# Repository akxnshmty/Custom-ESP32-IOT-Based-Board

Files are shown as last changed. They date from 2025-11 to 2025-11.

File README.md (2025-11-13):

# Custom-ESP32-IOT-Based-Board
Custom Multi-Sensor IoT Board with SD Card, Flash Memory, Microphone & High-Speed Routing

This project is a fully custom 4-layer IoT development board built around the ESP32, integrating multiple peripherals such as an SD card interface, external flash memory, I²C sensors, and an onboard microphone. It is designed as a compact, enclosure-ready hardware platform suitable for embedded, IoT, and data-logging applications.

⸻

🚀 Features
	•	ESP32-WROOM based core controller
	•	SD Card interface for data logging
	•	Flash memory IC for additional storage
	•	On-board microphone for audio input
	•	I²C sensor interface for environmental/IMU sensors
	•	User GPIO headers for expansion
	•	4-layer PCB with dedicated ground and power planes
	•	Mounting holes for enclosure integration
	•	Custom 3D models for accurate visualization
	•	Manual routing (0% autorouter) for full design control

⸻

🧩 Hardware Overview

4-Layer Stackup
	•	Layer 1 (Top): Components + High-speed signal routing
	•	Layer 2: Solid GND plane for low-noise return paths
	•	Layer 3: Power plane (5V + 3.3V distribution)
	•	Layer 4 (Bottom): Signal routing + copper zones

This architecture improves signal integrity, noise immunity, and routing efficiency, especially for the SD card, flash memory, and microphone circuits.

⸻

🔧 Key Technical Highlights

Manual Routing
	•	Differential pair routing
	•	Length matching for timing-critical nets
	•	I²C bus routing for sensors
	•	High-speed clock lines
	•	Optimized power traces
	•	Dedicated copper zones for GND and power
	•	Via stitching for ground reinforcement

Design & Validation
	•	Full manual DRC debugging
	•	Fixed annular ring and clearance violations
	•	Added test points, accessible GPIO, and labeled connectors
	•	Optimized analog routing for microphone stage

Mechanical Integration
	•	Exported STEP and WRL models
	•	Assembled 3D view for enclosure planning
	•	Added mounting holes
	•	Custom silkscreen signature

Firmware (Coming Soon)
	•	SD card logging demo
	•	Sensor reading script (I²C)
	•	Microphone input test
	•	Wi-Fi provisioning & OTA updates

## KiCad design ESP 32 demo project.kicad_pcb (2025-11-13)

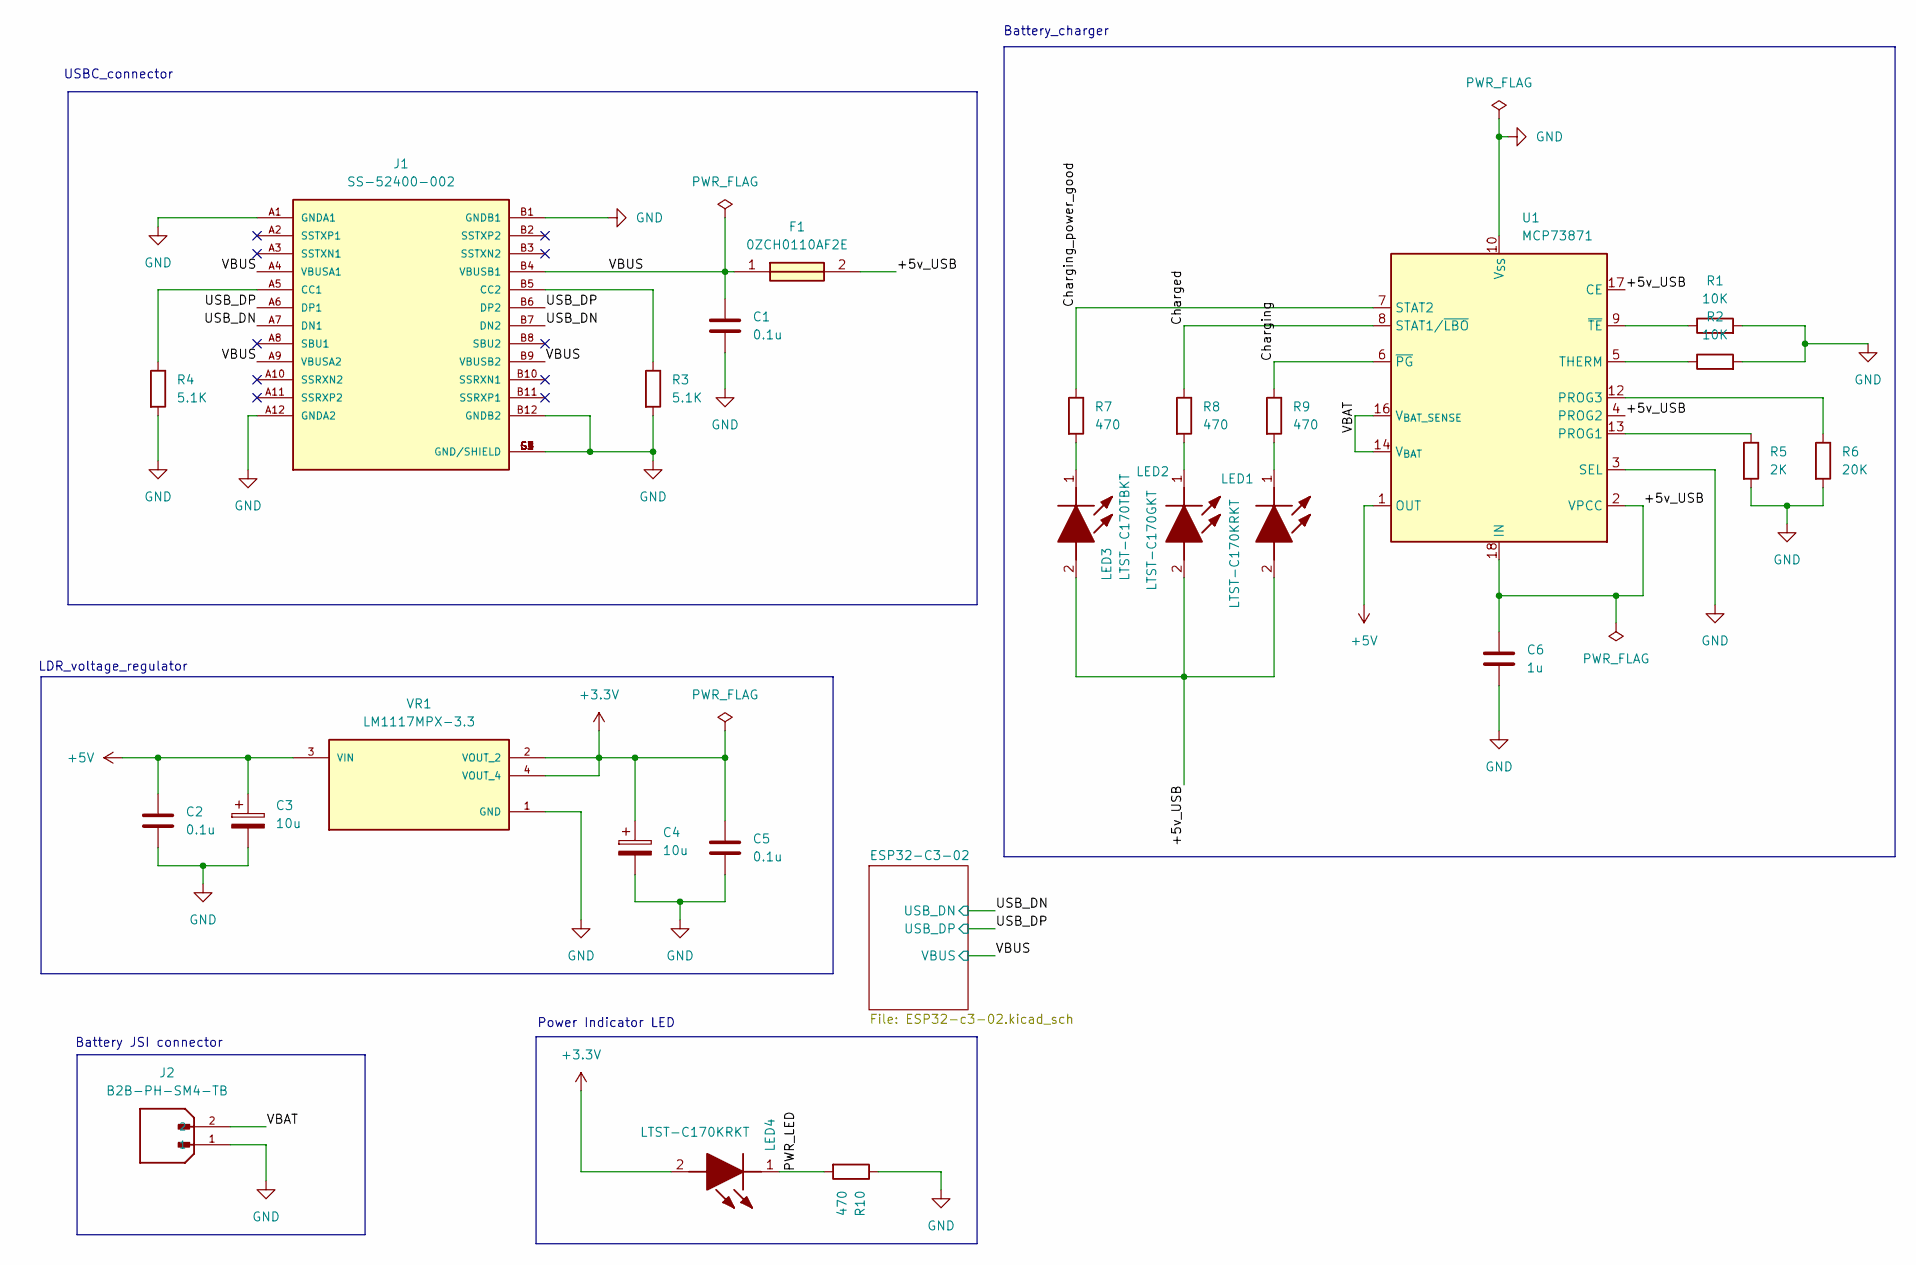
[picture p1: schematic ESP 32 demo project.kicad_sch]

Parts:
C1, C2, C5: 0.1u; C_0805_2012Metric
C3, C4: 10u; T491A
C6: 1u; C_0805_2012Metric
F1: 0ZCH0110AF2E; FUSC3226X100N; Manufacturer_Part_Number 0ZCH0110AF2E
J1: SS-52400-002; BELFUSE_SS-52400-002; PARTREV A0
J2: B2B-PH-SM4-TB; JST_B2B-PH-SM4-TB; PARTREV N/A
LED1, LED4: LTST-C170KRKT; LEDC2012X120N; Manufacturer_Part_Number LTST-C170KRKT; Mouser Part Number 859-LTST-C170KRKT
LED2: LTST-C170GKT; LEDC2012X120N; Manufacturer_Part_Number LTST-C170GKT; Mouser Part Number 859-LTST-C170GKT
LED3: LTST-C170TBKT; LEDC2012X120N; Manufacturer_Part_Number LTST-C170TBKT; Mouser Part Number 859-LTST-C170TBKT
R1, R2: 10K; R_0805_2012Metric
R3, R4: 5.1K; R_0805_2012Metric
R5: 2K; R_0805_2012Metric
R6: 20K; R_0805_2012Metric
R7, R8, R9, R10: 470; R_0805_2012Metric
U1: MCP73871; QFN-20-1EP_4x4mm_P0.5mm_EP2.5x2.5mm
VR1: LM1117MPX-3.3; VREG_LM1117MPX-3.3

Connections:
+3.3V: C4.1, C5.1, LED4.2 (A), VR1.2 (VOUT_2), VR1.4 (VOUT_4); also elsewhere on the board
/Charged: R8.1, U1.8 (STAT1/~LBO)
/Charging: R9.1, U1.6 (~PG)
/Charging_power_good: R7.1, U1.7 (STAT2)
/PWR_LED: LED4.1 (K), R10.2; also elsewhere on the board
/USB_DN: J1.A7 (DN1), J1.B7 (DN2); also elsewhere on the board
/USB_DP: J1.A6 (DP1), J1.B6 (DP2); also elsewhere on the board
/VBAT: J2.2, U1.14 (V_{BAT}), U1.15 (V_{BAT}), U1.16 (V_{BAT_SENSE})
/VBUS: C1.1, F1.1, J1.A4 (VBUSA1), J1.A9 (VBUSA2), J1.B4 (VBUSB1), J1.B9 (VBUSB2); also elsewhere on the board
unnamed: J1.A5 (CC1), R4.1
unnamed: J1.B5 (CC2), R3.1
unnamed: LED1.1 (K), R9.2
unnamed: LED2.1 (K), R8.2
unnamed: LED3.1 (K), R7.2
unnamed: R5.1, U1.13 (PROG1)
unnamed: R6.1, U1.12 (PROG3)
unnamed: R2.1, U1.5 (THERM)
unnamed: R1.1, U1.9 (~TE)

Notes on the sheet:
Battery JSI connector
Power Indicator LED
LDR_voltage_regulator
Battery_charger
USBC_connector

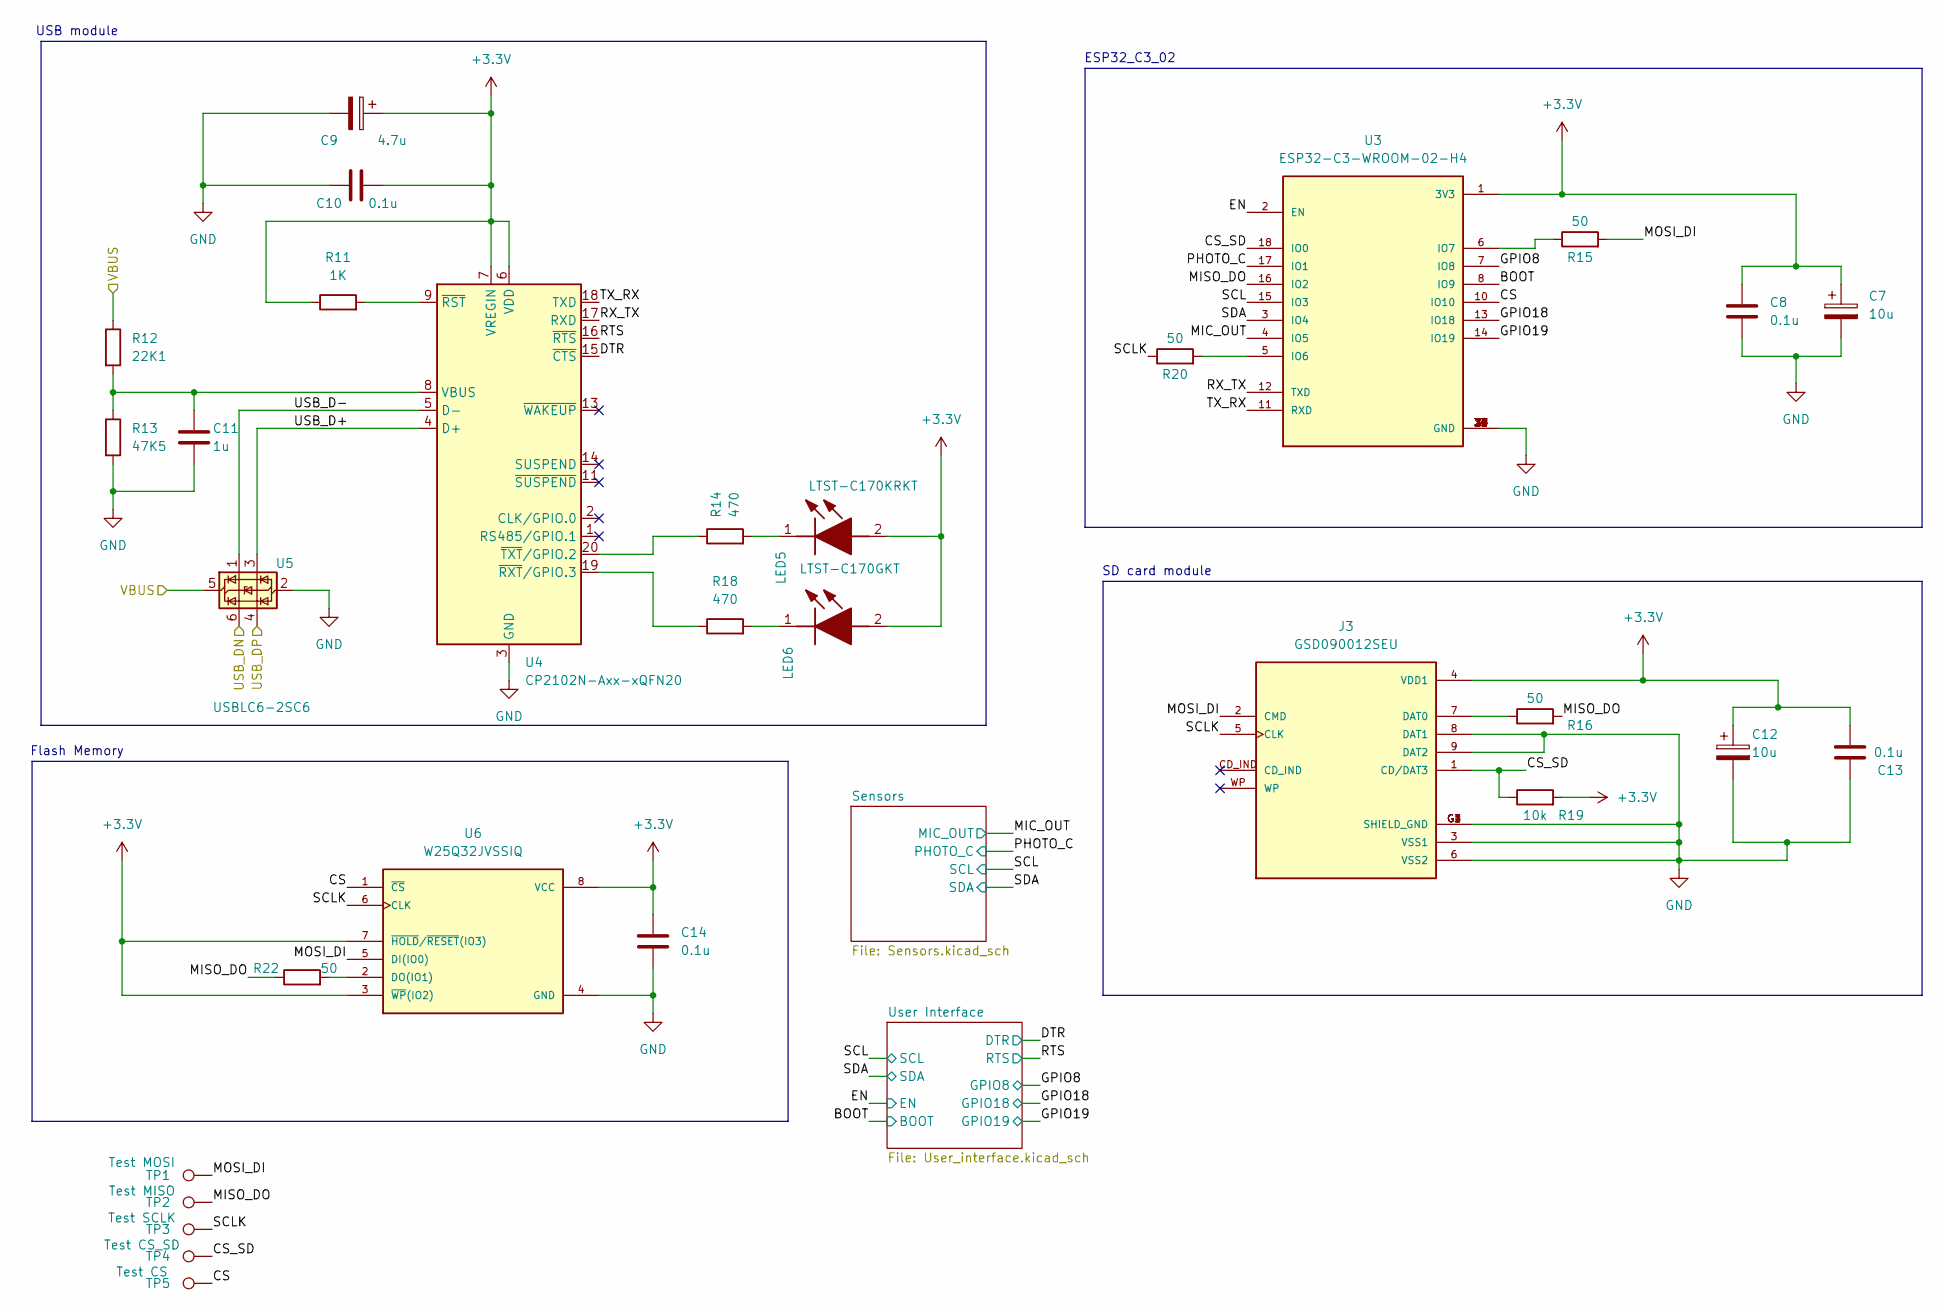
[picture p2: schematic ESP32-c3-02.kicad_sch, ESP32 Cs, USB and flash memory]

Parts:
C7, C12: 10u; T491A
C8, C10, C13, C14: 0.1u; C_0805_2012Metric
C9: 4.7u; T491A
C11: 1u; C_0805_2012Metric
J3: GSD090012SEU; AMPHENOL_GSD090012SEU; PARTREV E
LED5: LTST-C170GKT; LEDC2012X120N; Manufacturer_Part_Number LTST-C170GKT; Mouser Part Number 859-LTST-C170GKT
LED6: LTST-C170KRKT; LEDC2012X120N; Manufacturer_Part_Number LTST-C170KRKT; Mouser Part Number 859-LTST-C170KRKT
R11: 1K; R_0805_2012Metric
R12: 22K1; R_0805_2012Metric
R13: 47K5; R_0805_2012Metric
R14, R18: 470; R_0805_2012Metric
R15, R16, R20, R22: 50; R_0805_2012Metric
R19: 10k; R_0805_2012Metric
TP1: Test MOSI; TestPoint_Pad_D1.0mm
TP2: Test MISO; TestPoint_Pad_D1.0mm
TP3: Test SCLK; TestPoint_Pad_D1.0mm
TP4: Test CS_SD; TestPoint_Pad_D1.0mm
TP5: Test CS; TestPoint_Pad_D1.0mm
U3: ESP32-C3-WROOM-02-H4; MODULE_ESP32-C3-WROOM-02-H4
U4: CP2102N-Axx-xQFN20; SiliconLabs_QFN-20-1EP_3x3mm_P0.5mm_EP1.8x1.8mm
U5: USBLC6-2SC6; SOT-23-6
U6: W25Q32JVSSIQ; SOIC127P790X216-8N; M_PART_NUMBER W25QXX

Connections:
+3.3V: C7.1, C8.1, C9.1, C10.1, C12.1, C13.2, C14.1, J3.4 (VDD1), LED5.2 (A), LED6.2 (A), R11.1, R19.2, U3.1 (3V3), U4.6 (VDD), U4.7 (VREGIN), U6.3 (~WP(IO2)), U6.7 (~HOLD/~RESET(IO3)), U6.8 (VCC); also elsewhere on the board
/ESP32-C3-02/BOOT: U3.8 (IO9); also elsewhere on the board
/ESP32-C3-02/CS: TP5.1, U3.10 (IO10), U6.1 (~CS)
/ESP32-C3-02/CS_SD: J3.1 (CD/DAT3), R19.1, TP4.1, U3.18 (IO0)
/ESP32-C3-02/DTR: U4.15 (~CTS); also elsewhere on the board
/ESP32-C3-02/EN: U3.2 (EN); also elsewhere on the board
/ESP32-C3-02/GPIO8: U3.7 (IO8); also elsewhere on the board
/ESP32-C3-02/GPIO18: U3.13 (IO18); also elsewhere on the board
/ESP32-C3-02/GPIO19: U3.14 (IO19); also elsewhere on the board
/ESP32-C3-02/MIC_OUT: U3.4 (IO5); also elsewhere on the board
/ESP32-C3-02/MISO_DO: R16.2, R22.1, TP2.1, U3.16 (IO2)
/ESP32-C3-02/MOSI_DI: J3.2 (CMD), R15.2, TP1.1, U6.5 (DI(IO0))
/ESP32-C3-02/PHOTO_C: U3.17 (IO1); also elsewhere on the board
/ESP32-C3-02/RTS: U4.16 (~RTS); also elsewhere on the board
/ESP32-C3-02/RX_TX: U3.12 (TXD), U4.17 (RXD)
/ESP32-C3-02/SCL: U3.15 (IO3); also elsewhere on the board
/ESP32-C3-02/SCLK: J3.5 (CLK), R20.1, TP3.1, U6.6 (CLK)
/ESP32-C3-02/SDA: U3.3 (IO4); also elsewhere on the board
/ESP32-C3-02/TX_RX: U3.11 (RXD), U4.18 (TXD)
/ESP32-C3-02/USB_D+: U4.4 (D+), U5.3 (I/O2)
/ESP32-C3-02/USB_D-: U4.5 (D-), U5.1 (I/O1)
/USB_DN: U5.6 (I/O1); also elsewhere on the board
/USB_DP: U5.4 (I/O2); also elsewhere on the board
/VBUS: R12.1, U5.5 (VBUS); also elsewhere on the board
unnamed: J3.7 (DAT0), R16.1
unnamed: LED5.1 (K), R14.2
unnamed: LED6.1 (K), R18.2
unnamed: R20.2, U3.5 (IO6)
unnamed: R15.1, U3.6 (IO7)
unnamed: C11.1, R12.2, R13.1, U4.8 (VBUS)
unnamed: R11.2, U4.9 (~RST)
unnamed: R18.1, U4.19 (~RXT/GPIO.3)
unnamed: R14.1, U4.20 (~TXT/GPIO.2)
unnamed: R22.2, U6.2 (DO(IO1))

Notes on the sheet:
Flash Memory
ESP32_C3_02
SD card module
USB module

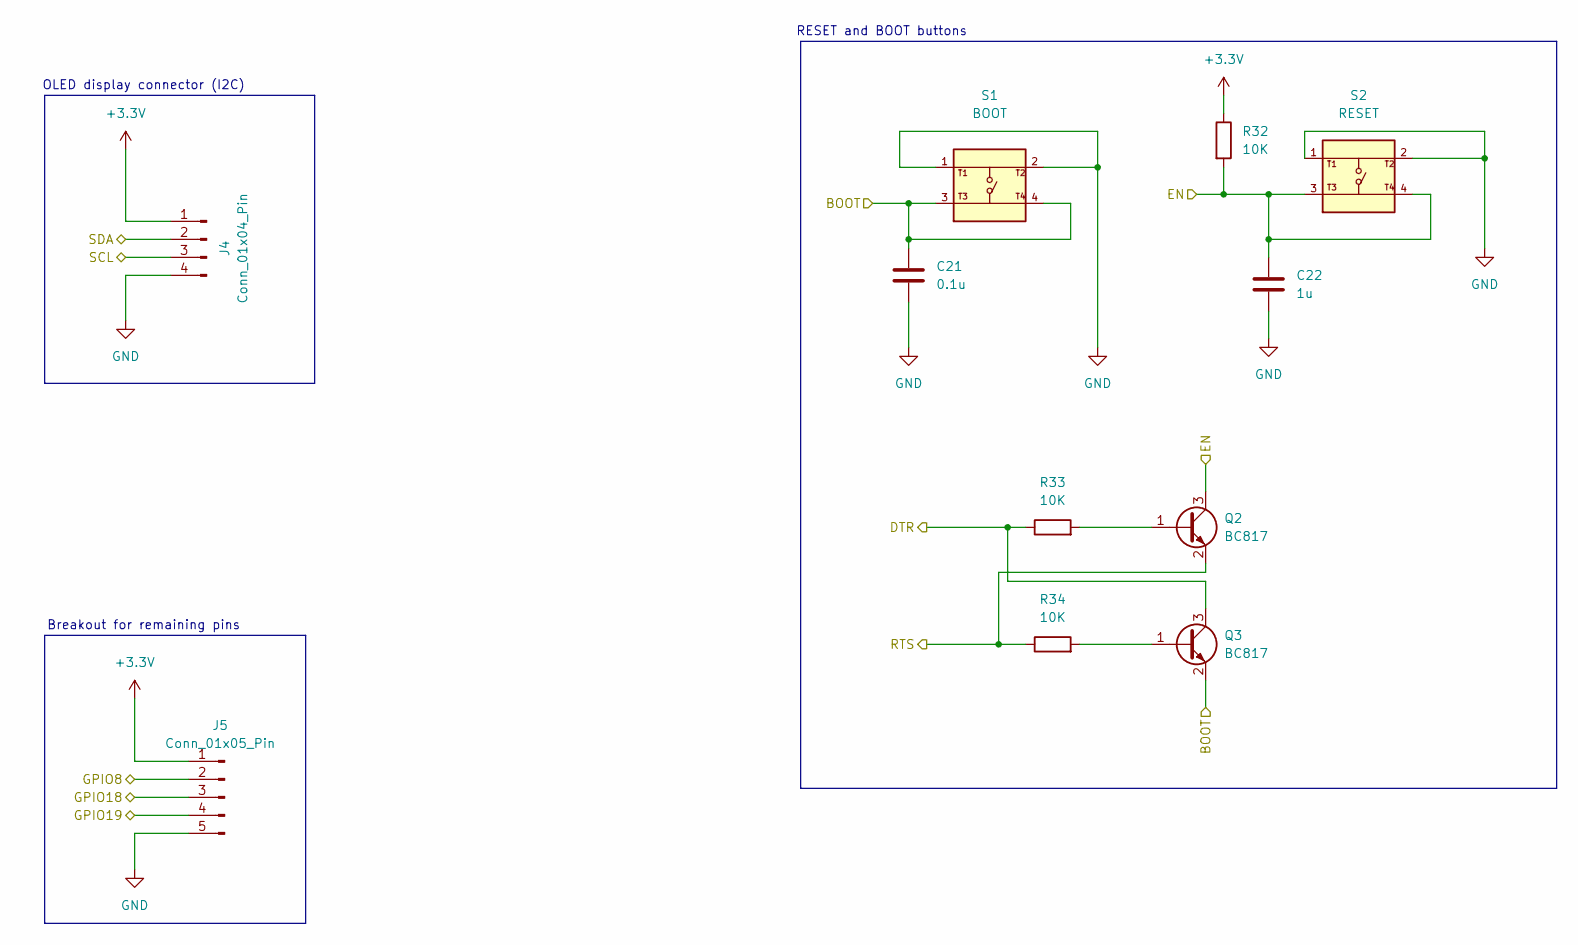
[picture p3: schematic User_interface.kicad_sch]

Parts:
C21: 0.1u; C_0805_2012Metric
C22: 1u; C_0805_2012Metric
J4: Conn_01x04_Pin; PinHeader_1x04_P2.54mm_Vertical
J5: Conn_01x05_Pin; PinHeader_1x05_P2.54mm_Vertical
Q2, Q3: BC817; SOT-23
R32, R33, R34: 10K; R_0805_2012Metric
S1: BOOT; SW_USLPT2819DT2TR; PARTREV P
S2: RESET; SW_USLPT2819DT2TR; PARTREV P

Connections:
+3.3V: J4.1, J5.1, R32.1; also elsewhere on the board
/ESP32-C3-02/BOOT: C21.1, Q3.2 (E), S1.3, S1.4; also elsewhere on the board
/ESP32-C3-02/DTR: Q3.3 (C), R33.1; also elsewhere on the board
/ESP32-C3-02/EN: C22.1, Q2.3 (C), R32.2, S2.3, S2.4; also elsewhere on the board
/ESP32-C3-02/GPIO8: J5.2; also elsewhere on the board
/ESP32-C3-02/GPIO18: J5.3; also elsewhere on the board
/ESP32-C3-02/GPIO19: J5.4; also elsewhere on the board
/ESP32-C3-02/RTS: Q2.2 (E), R34.1; also elsewhere on the board
/ESP32-C3-02/SCL: J4.3; also elsewhere on the board
/ESP32-C3-02/SDA: J4.2; also elsewhere on the board
unnamed: Q2.1 (B), R33.2
unnamed: Q3.1 (B), R34.2

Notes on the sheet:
RESET and BOOT buttons
OLED display connector (I2C)
Breakout for remaining pins

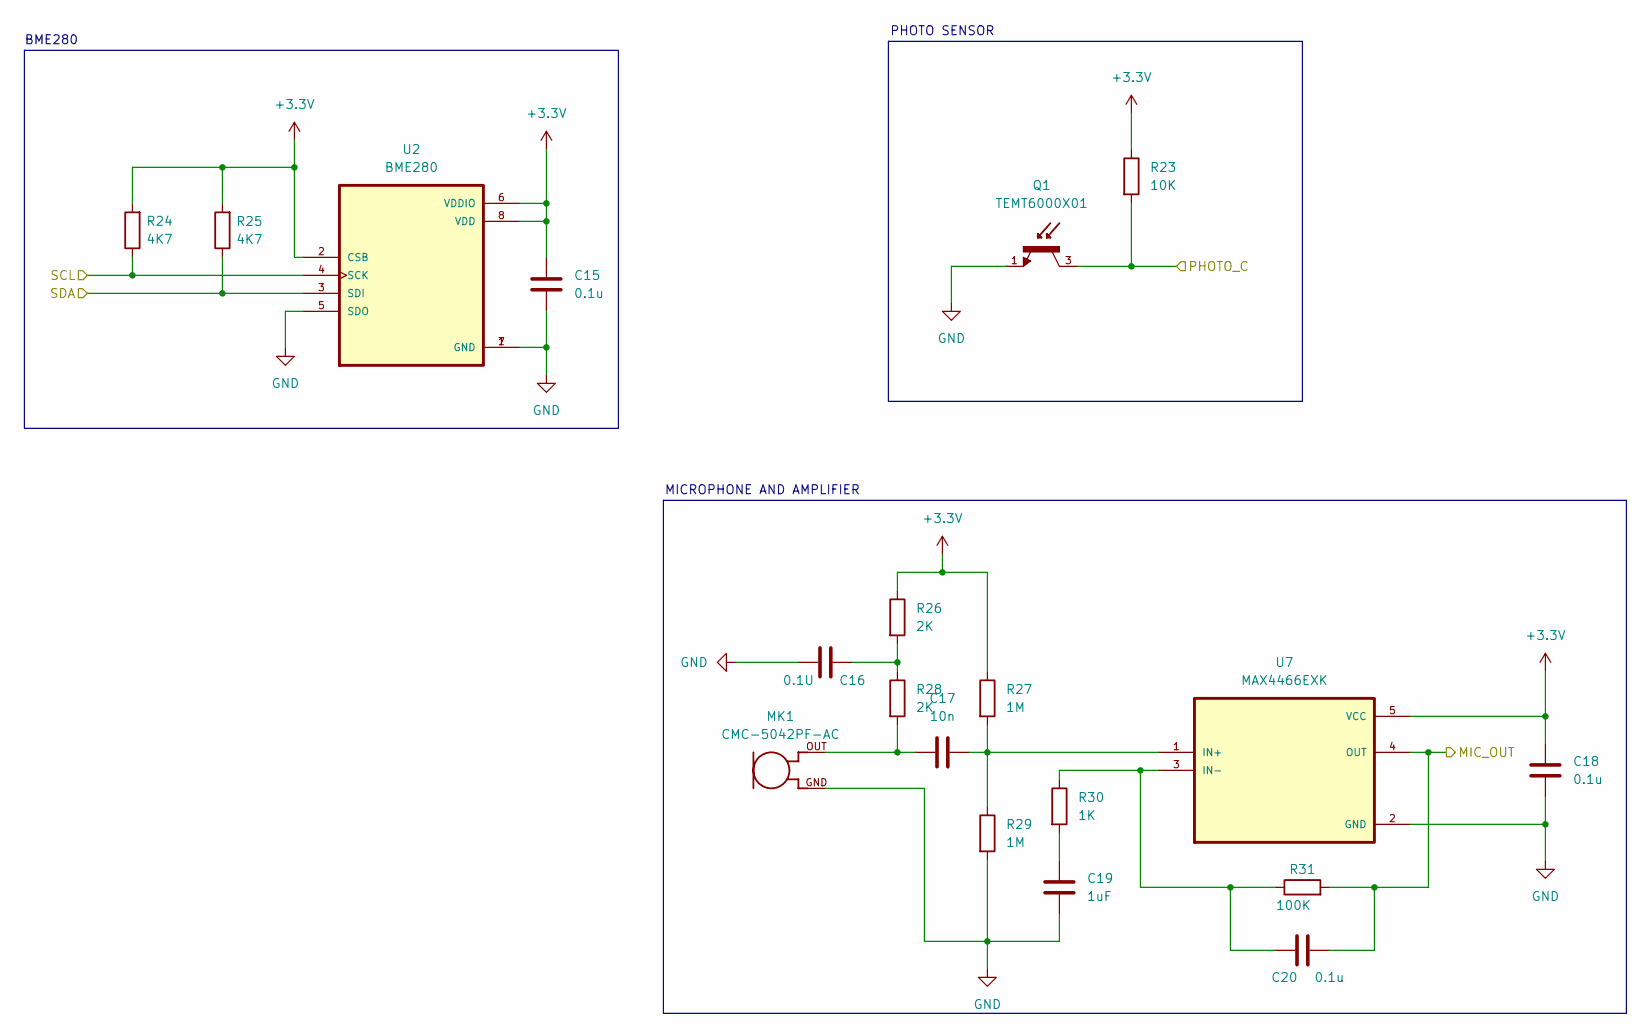
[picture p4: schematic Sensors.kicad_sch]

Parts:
C15, C18, C20: 0.1u; C_0805_2012Metric
C16: 0.1U; C_0805_2012Metric
C17: 10n; C_0805_2012Metric
C19: 1uF; C_0805_2012Metric
MK1: CMC-5042PF-AC; CUI_CMC-5042PF-AC
Q1: TEMT6000X01; TRANS_TEMT6000X01; PARTREV 1.9
R23: 10K; R_0805_2012Metric
R24, R25: 4K7; R_0805_2012Metric
R26, R28: 2K; R_0805_2012Metric
R27, R29: 1M; R_0805_2012Metric
R30: 1K; R_0805_2012Metric
R31: 100K; R_0805_2012Metric
U2: BME280; PSON65P250X250X100-8N
U7: MAX4466EXK; SOT65P210X110-5N

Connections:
+3.3V: C15.1, C18.1, R23.1, R24.2, R25.2, R26.1, R27.1, U2.2 (CSB), U2.6 (VDDIO), U2.8 (VDD), U7.5 (VCC); also elsewhere on the board
/ESP32-C3-02/MIC_OUT: C20.2, R31.2, U7.4 (OUT); also elsewhere on the board
/ESP32-C3-02/PHOTO_C: Q1.3, R23.2; also elsewhere on the board
/ESP32-C3-02/SCL: R24.1, U2.4 (SCK); also elsewhere on the board
/ESP32-C3-02/SDA: R25.1, U2.3 (SDI); also elsewhere on the board
unnamed: C16.2, R26.2, R28.1
unnamed: C17.1, MK1.OUT, R28.2
unnamed 31: C19.1, R30.2; also elsewhere on the board
unnamed: C17.2, R27.2, R29.1, U7.1 (IN+)
unnamed: C20.1, R30.1, R31.1, U7.3 (IN-)

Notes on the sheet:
MICROPHONE AND AMPLIFIER
BME280
PHOTO SENSOR

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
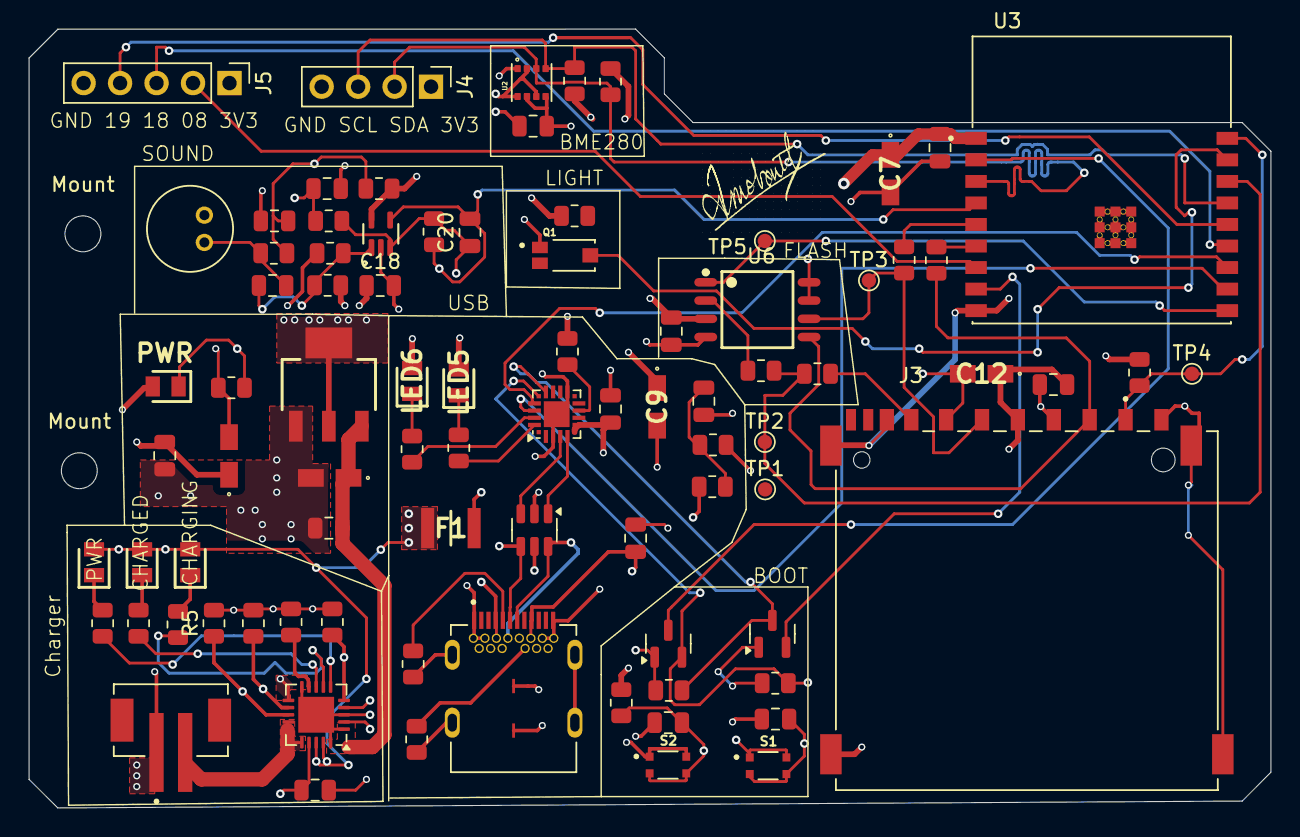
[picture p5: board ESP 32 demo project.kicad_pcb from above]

Board: 4 copper layers, 86.5 x 54.3 mm, 87 parts (0 on the bottom side), 58 nets.

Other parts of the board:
C: 1uF; C_0805_2012Metric
Mount: MountingHole_2.5mm
Mount#2: MountingHole_2.5mm
PWR: LTST-C170KRKT; LEDC2012X120N

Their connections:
+3.3V: PWR.2 (A); also elsewhere on the board
/PWR_LED: PWR.1 (K); also elsewhere on the board
unnamed 31: C.1; also elsewhere on the board

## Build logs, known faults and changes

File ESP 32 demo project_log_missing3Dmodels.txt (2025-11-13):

[('PWR', '/Users/aakankshmohanty/Desktop/Projects/PCB design/Files/ESP 32 demo project/LTST-C170KRKT.stp'), ('C12', '/Users/aakankshmohanty/Desktop/Projects/PCB design/Files/ESP 32 demo project/T491A106K010AT7280.stp'), ('LED1', '/Users/aakankshmohanty/Desktop/Projects/PCB design/Files/ESP 32 demo project')]
